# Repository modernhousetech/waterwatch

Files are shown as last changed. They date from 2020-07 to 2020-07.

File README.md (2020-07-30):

# WaterWatch
[Please note that the project while working, is not complete at this point, and has not been fully tested or debugged. The Home Assistant code and the Node-RED code has not been posted yet, but it will be soon. The documentation below is incomplete. There will be more to come] 

WaterWatch Home device ready for installation

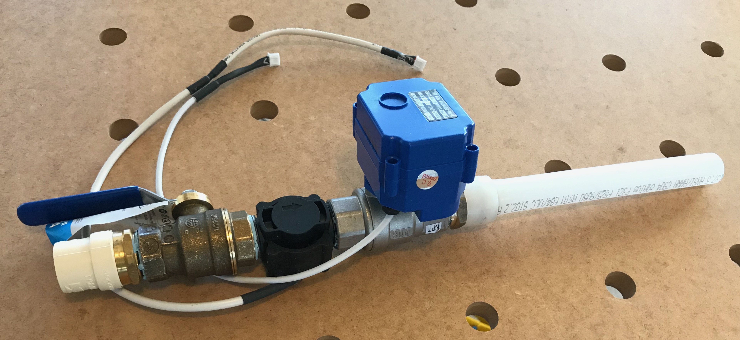
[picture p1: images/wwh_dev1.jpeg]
WaterWatch Home device ready for installation


## Introduction
WaterWatch is a hardware/software project to monitor home water usage and to automatically turn off the water supply if a leak is suspected.

There are two versions of the project. One that monitors and protects irrigation (wwi) and another that monitors and protects a whole house (wwh). The wwi project is much simpler, although it does require a third-party smart irrigation device to integrate with. The wwh project has its own motorized valve and attempts to protect water leaks of all kinds including irrigation leaks.

The wwh device installs at your home's water entrance location. The wwi device installs right before your existing irrigation valves. While the wwh device does provide irrigation leak protection, there is utility in having both devices installed in a single home. The wwi device will give you better irrigation water usage values and times than the wwh device, and it will give you additional protection as it can monitor irrigation with greater precision. The wwi device, of course, offers no protection against household leaks.

Features:
* Automatically shuts off water flow based on a wide variety and extensible criteria
* Uses open and popular IOT and smart home standards and technologies
* Integrates with third-party devices and sensors such as water leak sensors and smart irrigation systems
* Integrates into the major smart home user interface devices such as Alexa and Google Assistant
* Accumulates hourly and daily water usage totals. These are sent to the controller on an hourly basis and are also stored in the device and are available on demand
* Accumulates session water usage totals. WaterWatch automatically creates anonymous sessions based on continuous water usage that meets a certain threshold. For instance, if someone showers there will be a water flow start and a stop. If during that start and stop there is sufficient water usage, then WaterWatch will consider that a "session" and will report it to the controller (Home Assistant). The controller can then report that to the user and also calculate costs based on current water rates. Another useful example of an anonymous sessions would be something like filling up a hot tub. How much water did you use and at what cost? Since WaterWatch Home monitors the water flow of the entire house and other water can flow simultaneously, common sense will have to be used to know if the session was truly just one water event.
* Accumulates named session water usage totals. A named session is similar to an anonymous session except the start and stop times are specified by the controller, and it is given a name. The usefulness of this feature can probably best be explained using an example. Your washing machine (an ordinary non-smart appliance) is connected to a smart plug that monitors power usage. When Home Assistant determines that the washing machine has started a wash (based on power usage data sent from the smart plug) it notifies WaterWatch that a washer load has started. WaterWatch then tells the WaterWatch device to start a named session called "Washer." When Home Assistant subsequently notifies WaterWatch that the load is finished, WaterWatch will tell the device to stop the session. The device then notifies the controller of all water that was used during the start and stop times. WaterWatch then notifies the user of the amount and cost of water used during the wash, as well as the electrical power cost. As mentioned above, common sense needs to be used to know if the water usage was from just the washing machine.

The project uses the following technologies:

Hardware both wwi and wwh:
* [ESP32 development board](https://www.amazon.com/s?k=esp32&i=electronics) 
* [Water flow meter](https://www.amazon.com/gp/product/B079HFY2TY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)
* Various electronic parts and wire
* Various plumbing connectors

Hardware wwh only:
* [Motorized valve](https://www.amazon.com/gp/product/B071YBPDSL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) 
* [Water leak sensors](https://www.amazon.com/gp/product/B07D39MSZS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) (optional) We've used Aqara sensors which also require an Aqara hub. Integration to the WaterWatch system is through Home Assistant and Node-RED. Any detector that integrates into Home Assistant could be used.

Software:
* [Esphome](https://esphome.io) Esphome is a device software development platform. We define our sensors and other devices using esphome yaml syntax and then transition the logic to the C++ code.
* [MQTT](http://mqtt.org) Communication to and from The WaterWatch WiFi device is through the MQTT protocol.
* [Node-RED](https://nodered.org) The logic outside of the device is written in Node-RED. Node-RED is a well-supported, open-source IOT platform. Programming in Node-RED is primarily in Javascript.
* [Home Assistant](https://www.home-assistant.io) Home Assistant is a well-supported, open source, smart home platform that allows us to integrate our device and code with the many other devices and sub-systems that Home Assistant supports. It also provides us a UI and notification platform, and hosts the MQTT server and Node-RED.

Detailed software design instructions will follow.

## Overall design

A one line communication diagram is: device<->MQTT<->Node-RED<->Home Assistant

At its most basic, the project produces an ESP32 device that connects to a water flow sensor and controls a motorized water valve (wwh only). It communicates using WiFi to an MQTT server, which in turn communicates with the smart home system (Home Assistant). 

When water flow or usage exceeds the values provided by the smart home software, the device acts by sending an alarm and (on the wwh device) turning off the valve.

The software in the smart home system is more sophisticated because we can leverage reliable systems in the smart home software, such as occupancy sensors, the on/off status of water using appliances (such as washing machines), irrigation valves that are open, and smart phone and smart device notification features (such as Alexa and Google Assistant). For instance, when the smart home software sets a state of "house is unoccupied" then WaterWatch can tell the WaterWatch device to alarm on *any* water usage (or very little to accommodate running washers and dishwashers). If our washer is powered on, then the smart home software can detect that and we can allow a specific amount of water flow while it is on. 

The smart home software can also integrate WaterWatch with water detection monitors. When a sensor detects water (under a sink for instance), WaterWatch is notified and it will instruct the device to turn off the house water valve.

In the future we would like to implement "signature" water flow events. A very simple signature event would be, for instance, a toilet flush. The water flow increases a certain amount for certain amount of time. When that is detected we know what that water flow was and we can then do something with this information. At this point we can send a water flow "signature" to the device, but the actual detection of the event is only partially implemented. 

### Prerequisites

* Home Assistant running an MQTT server and hosting Node-RED. It would possible to adapt WaterWatch to other smart home platform, such as OpenHAB, that can use MQTT or Node-RED.

* [Esphome setup for a command-line environment](https://esphome.io/guides/getting_started_command_line.html). While the web based ESPHome dashboard usage of Esphome would work, that feature loses it utility for a project that supports multiple configurations, is more complex than just one or more sensors reporting status, and is mostly C++ based.

### WaterWatch Home (wwh) hardware design

WaterWatch Home (wwh) device ready for installation

WaterWatch Home (wwh) ready for installation

This particular unit will attach to the existing house plumbing at the water house entrance using PVC from the street and Uponor PEX to transition to the house's copper piping. The small black device in the middle is the water flow sensor and the blue and metal device is the motorized valve. Both of these devices attach to the WaterWatch CPU using the white cables visible in the image. The manual valve in the image is not necessary for the WaterWatch system, but is there to replace an existing manual valve at the installation location.

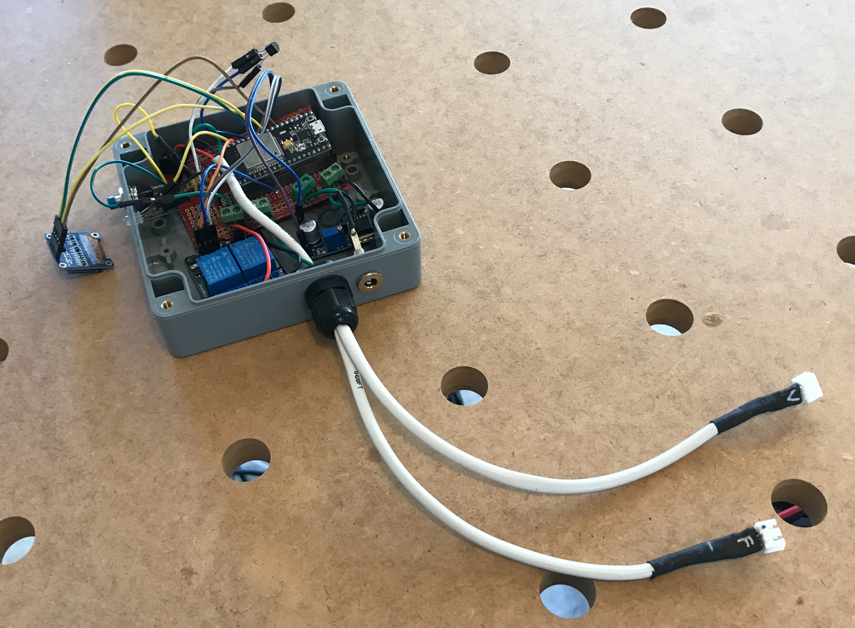
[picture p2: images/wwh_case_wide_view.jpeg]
WaterWatch Home CPU


WaterWatch Home CPU

#### Prerequisites

#### Plumbing Components:

#### CPU Components:
* ESP32 Board[ESP-32S-Development-Board](https://amzn.to/3go0uMI)
* [2 Channel Relay](https://amzn.to/2ztyLcZ)
* [Buck converter LM2596](https://amzn.to/2yAE8Xq)
* [12v-Power-Supply-Single](https://amzn.to/3d2AhkF) These are excellent power supplies that put out a reliable steady 12 volts
* or [12v-Power-Supply-5-pack](https://amzn.to/2X5wtdf) If you need more than two then this five pack is a good deal
* [OLED LCD Display](https://amzn.to/2ZzWX85)
* [Dallas-Temperature-Sensor DS18B20](https://amzn.to/3egIFNS) 
* [PCB-Mount-Screw-Terminal](https://amzn.to/2TA10xv)
* [DC-Power-Jack-Socket](https://amzn.to/2zim1pF)
* [Momentary-switch](https://amzn.to/2TCt973)
* [3-Conductor-Cable](https://amzn.to/3gnVBUa)
* [Cable-Gland](https://amzn.to/2Zy9t89)
* [Hook-up-Wire-Kit](https://amzn.to/36udw76)
* [Breadboard](https://amzn.to/2TAdzZE)
* or [Breadboard-kit](https://amzn.to/3eeRYhd)
* [Dupont-cables](https://amzn.to/2XqUVo3)
* [Cable-connectors](https://amzn.to/2yA37Kw) Other suitable three conductor connectors will do -- this is just what I used. These work well, although they are not waterproof. If weather-proofing is needed, I recommend sealing the connection with heat shrink tubing over a water-resistant non-conductive gel (or ordinary caulk which should be non-conductive once dry), then labeling the joint so the next user knows where it is detachable.
* [Crimping-tool-for-above](https://amzn.to/3ehfoCQ) 
* [Enclosure](https://amzn.to/2XFp3MT) While this is not the enclosure I used in the image, it is of a similar size (120mm x 120mmm x 60mm, external). I had to trim the breadboard to get it to fit in the enclosure you see in the image, so either this size board or the component layout is not perfect. 

### WaterWatch Irrigation (wwi) hardware design

#### Prerequisites

* A smart irrigation device that integrates into the same smart home platform used for WaterWatch.

Copyright 2020 Brenton Olander

[The Amazon links above are affiliate links, which means that I get a little bit of money from Amazon should you purchase using the link. The price for you will be exactly the same whether you purchase using the link or not. If it is convenient for you to purchase using the link then thank you very much.]

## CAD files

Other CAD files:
3d_models/wwi_mini.skp

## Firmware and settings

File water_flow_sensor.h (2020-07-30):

#pragma once

#include "esphome.h"
#include "pulse_counter_sensor.h"
using namespace esphome;
using namespace sensor;
using namespace pulse_counter;
#include "translation_unit.h"
#include "signature.h"

// This is the units per minute water flow value when presumably there is no water flow.
// If the plumbing system is working correctly this should be zero.
extern pulse_counter::pulse_counter_t* g_pulses_base;



class WaterflowSensor: public pulse_counter::PulseCounterSensor {

    // wf_off mode or wf_on mode. 
    // wf_off mode is when water flow <= 0 and wf_on mode is when water flow > 0

    bool in_wf_on_mode_ = false;

    int pin_;
    TranslationManager& xlate_mgr_;
    SignatureManager signature_mgr_;

    static constexpr float report_period_wf_off_mode_secs_default_ = 15.0f;
    static constexpr float report_period_wf_on_mode_secs_default_ = 2.0f;


    // We get updates every <update_interval_default> but report at
    // schedule below when we are in wf_off mode
    float report_period_wf_off_mode_secs_ = report_period_wf_off_mode_secs_default_; 
    float report_period_wf_on_mode_secs_ = report_period_wf_on_mode_secs_default_; 

    static constexpr float update_interval_secs_default_ = 1.0f;

    float update_interval_secs_ = update_interval_secs_default_; 

    struct ReportPeriod {

        pulse_counter_t pulses_total_ = 0.0f;
        int secs_ = 0;
        int last_report_period_secs_ = 0.0f;
        bool report_only_on_change = false;
        
        // Special to report on next add call
        // Currently this is used to get an initial
        // report as soon as possible on start-up so
        // user can see something when we start.
        bool report_on_next_add = false;

        static const int wf_is_changed_delta_ = 10;

        int report_period_secs_;

        pulse_counter_t last_pulses_ = -1;

        ReportPeriod(int report_period_secs):
            report_period_secs_(report_period_secs) {
            reset();
        }

        void set_report_period_secs(int report_period_secs) {
            report_period_secs_ = report_period_secs;
        }

        int get_report_period_secs() const {
            return report_period_secs_;
        }

        int get_last_report_period_secs() const {
            return last_report_period_secs_;
        }

        bool is_report_only_on_change() const { return report_period_secs_ == 0; }

        bool add(pulse_counter_t pulses, int secs) {
            pulses_total_ += pulses;
            secs_ += secs;
            bool change_of_pulses = abs(last_pulses_ - pulses) > wf_is_changed_delta_;
            last_pulses_ = pulses;

            // ESP_LOGD("main", "report_period.add(%i) pulses_total=%i, secs total=%i"
            //     ", last_pulses=%i, change=%i, report_on_change=%i"
            //     ", report_period_secs=%i", 
            //     pulses, pulses_total_, secs_ , last_pulses_,  change_of_pulses,
            //     is_report_only_on_change(), report_period_secs_);  

            bool report = (is_report_only_on_change() && change_of_pulses) 
                || secs_ >= report_period_secs_ || report_on_next_add;
            report_on_next_add = false;

            return report;
        }

        float get_value_as_pulses_per_minute() {

            return (60.0f * pulses_total_) / float(secs_);
        }

        void reset() {
            pulses_total_ = 0;
            last_report_period_secs_ = secs_;
            secs_ = 0;
            last_pulses_ = -1;
        }
    } report_period_;

    public:

    WaterflowSensor(int pin, TranslationManager& xlate_mgr):
        pin_(pin),
        xlate_mgr_(xlate_mgr),
        signature_mgr_(xlate_mgr_),
        report_period_(report_period_wf_off_mode_secs_) {

        set_name("wf");
        set_unit_of_measurement("pulses/min");
        set_icon("mdi:pulse");
        set_accuracy_decimals(2);
        set_force_update(false);
    }

    void on_start_init( int report_period_wf_off_mode_secs,
                        int report_period_wf_on_mode_secs ) {

        ESP_LOGD("main", "on_start_init(%i, %i)",  
          report_period_wf_off_mode_secs, report_period_wf_on_mode_secs);
        set_pin(new GPIOPin(pin_, INPUT, false));

        set_report_period_wf_off_mode_secs(report_period_wf_off_mode_secs);
        set_report_period_wf_on_mode_secs(report_period_wf_on_mode_secs);
        report_period_.set_report_period_secs(report_period_wf_off_mode_secs_);
        // We want to report (publish) initially as soon as possible so
        // user can see something.
        report_period_.report_on_next_add = true;

        set_update_interval_secs(1);
        
        set_in_wf_on_mode(false);

        set_rising_edge_mode(pulse_counter::PULSE_COUNTER_INCREMENT);
        set_falling_edge_mode(pulse_counter::PULSE_COUNTER_DISABLE);
        set_filter_us(13);
    }

    // Modes:
    //      Normal
    //      Fast
    //      on change
    //      never on zero (=< base flow)
    void update() override {
        pulse_counter_t pulses = this->storage_.read_raw_value();

        if (report_period_.add(pulses, update_interval_secs_)) {
            float value = xlate_mgr_.current->convert_pulses_to_uom(report_period_.get_value_as_pulses_per_minute());
            // reset() below will save the secs of this period which
            // the app will retrieve using get_last_period_secs(). This is a
            // bit of  kludge which we use because we can't, as far as I know,
            // send more information when we publish_state(). TODO: we could easily use
            // an alternative to publish_state() to get this data to the app.
            report_period_.reset();
            this->publish_state(value);
        }

        //float value = (60000.0f * raw) / float(this->get_update_interval());  // per minute
        //value = xlate_->convert_pulses_to_uom(value);

        //if (!only_publish_on_change || )
        if (pulses > *g_pulses_base && !in_wf_on_mode()) {
            set_in_wf_on_mode(true);
        } else if (pulses <= *g_pulses_base && in_wf_on_mode()) {
            set_in_wf_on_mode(false);
        }

        // ESP_LOGD("main", "pulse counter: %i pulses,wf_on_mode(%i), rps(%i)", 
        //   pulses, in_wf_on_mode(), report_period_.get_report_period_secs());
        
    }

    void convert_uom(const char* from, float old_calibrate_factor=0) {
        signature_mgr_.convert_uom(from, old_calibrate_factor);
    }

    int get_report_period_secs() const {
        return report_period_.get_report_period_secs();
    }

    int get_last_report_period_secs() const {
        return report_period_.get_last_report_period_secs();
    }

    void set_report_period_wf_off_mode_secs(float secs) {
        report_period_wf_off_mode_secs_ = secs; 
        if (!in_wf_on_mode()) {
            report_period_.set_report_period_secs(report_period_wf_off_mode_secs_);
        }
    }
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

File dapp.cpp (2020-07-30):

// Copyright 2020 Brenton Olander

#include "esphome.h"
#include "dapp.h"


#define FW_VERSION_BASE "0.05.22"

#ifdef APP_DEBUG_MODE
#define FW_VERSION_DEBUG FW_VERSION_BASE"-D"
#else
#define FW_VERSION_DEBUG FW_VERSION_BASE
#endif

#if LOG_LEVEL > LOGLEVEL_HIGHEST_RELEASE_LEVEL
#define FW_VERSION FW_VERSION_DEBUG"-L:D"
#else
#define FW_VERSION FW_VERSION_DEBUG
#endif 

//#ifdef gpio::GPIOSwitch::GPIOSwitchRestoreMode
extern gpio::GPIOSwitch *valve_open;
extern gpio::GPIOSwitch *valve_close;
//#endif


dApp dapp;

#ifdef APP_LOG
AppLog app_log;
#endif

// Mirrors dapp.upm_base for the benefit of WaterUsage
float* g_upm_base;
pulse_counter::pulse_counter_t* g_pulses_base;

///////////////////////////////////////////////////////////////////////////////////////////
dApp::dApp() {

    // Global cheat for WaterUsage objects
    g_upm_base = &upm_base_;
    g_pulses_base = &pulses_base_;
}


// Called at on_boot level 600 where sensors are setup but wifi (and mqtt) are not
void _entry_point dApp::on_boot(const char* app, int wf_report_wf_off_interval_secs, int wf_report_wf_on_interval_secs) {

    APP_LOG_ENTER("on_boot()");

    SetStatusLED(1.0, 1.0, 1.0);

    app_ = app;

    wf_->on_start_init(wf_report_wf_off_interval_secs, wf_report_wf_on_interval_secs);

    calc_max_plus_values();

    makeMqttTopics(mqtt_client->get_topic_prefix());

    SetStatusLEDBasedOnValveStatus();

    on_boot_called = true;

    APP_LOG_LOG("} on_boot(app=%s, wf_off_interval_secs=%i, wf_on_interval_secs=%i", app,
      wf_report_wf_off_interval_secs, wf_report_wf_on_interval_secs); 

    APP_LOG_EXIT("on_boot");
  }


  void dApp::makeMqttTopics(const std::string& prefix) {

    mqtt_topic_prefix_ = prefix;

    mqttTopicClosedUsageState_ = prefix + mqttTopicClosedUsageState_;
    mqttTopicStat_ = prefix + mqttTopicStat_;
    mqttTopicProp_ = prefix + mqttTopicProp_;
    mqttSensorWfOverlimitStatus_ = prefix + mqttSensorWfOverlimitStatus_;
    mqttSensorWfCurrentUsageState_ = prefix + mqttSensorWfCurrentUsageState_;
    mqttSensorWfHourlyUsageStatus_ = prefix + mqttSensorWfHourlyUsageStatus_;
    mqttSensorWfDailyUsageStatus_ = prefix + mqttSensorWfDailyUsageStatus_;
    mqttSensorWfSessionUsageState_ = prefix + mqttSensorWfSessionUsageState_;
    mqttSensorWfNamedUsageState_ = prefix + mqttSensorWfNamedUsageState_;

  }

/* 
  Properties {

    [See https://en.wikipedia.org/wiki/List_of_tz_database_time_zones ]
    "timezone": "America/Phoenix",

    [Hourly usage totals can be saved in array in device.
    Use mqtt topic "<topic-prefix>/cmnd/get_closed_periods" to have
    waterwatch send array in mqtt json message topic
    "/sensor/wf/closed_usage/state".
    Use mqtt message topic "<topic-prefix>/cmnd/clear_closed" to
    clear this array and session array.]
    "closed_periods_max": 48,

    [Waterwatch supports 'gal' for gallons and gpm and 'L' for liters and lpm]
    "unit_of_measure": "gal",

    [Maximimum water flow. When above this level
    waterwatch will send out an alarm in mqtt topic
    "sensor/wf/over_limit/status" with payload "on" or "off"]
    "water_flow_max": 1.0,

    [At or below this level is considered "no water flow".
    Normally this should be 0, but a tolerance is permitted using
    this property in case zero is not possible perhaps because of a 
    leak that is not fixed immediately.]
    "water_flow_base": 0.0,

    [Adjust device water flow and usage using this value in case
    what waterwatch thinks is a gallon or a liter is not what you. 
    measure. Examples: 1.0 is unadjusted, 1.1 is a 10% adjustment upwards,
    0.9 is a 10% adjustment downwards. For instance, if you measure
    .5 gallons and waterwatch reports 1 gallon, you would use a 
    calibrate_factor of 0.5]
    "calibrate_factor": 1.1,


    [How long in seconds does an overlimit condition have to exist 
    before an alarm is raised? The integral "reporting period" in
    waterwatch is 15 seconds. "test_period_secs" must be a multiple
    of this reporting period. The default is the reporting period
    of 15 seconds. False alarms can also be avoided using the
    "initial_surge_secs" property.  ]
    "test_period_secs": 30,

    [If pipes are empty there can sometimes be an initial 
    surge of over limit water flow as the pipes are filled. 
    This propery allows a "grace" period when water first
    starts to flow to account for this. After water is flowing
    this property is ignored and only "test_period_secs" is
    observed.]
    "initial_surge_secs": 15,

    [Waterwatch keeps track of the water usage during a continuous period 
    of irrigating which we call a session. The next three properties
    control this feature]

    [How many sessions to save before overwriting oldest]
    "closed_sessions_max": 14

    [Sessions shorter than min_secs will be thrown out]
    "min_session_secs": 420,

    [When one zone valve closes and another opens there
    may be no water flow. How long to allow for this. (in
    the future these subs zones will alse be saved)]
    "end_session_secs": 180

    [How often we report water flow in seconds. "wf_off" mode is
    when there is no water flow, wf_on mode is when there is water flow.
    A value of 0 means to report only on change of flow. 
    Defaults in the code are: wf_off = 15, wf_on = 2. There are
    defaults in the common_substitutions.yaml as well that override the 
    code. At last check they are wf_off = 180, wf_on = 2
    (TODO: would it be better to use 0 to 
    mean "never report" and a negative number to mean "on change only"?)]
    "report_period_secs": {
      "wf_off": 0,  
      "wf_on": 0   
    }

    Other items needed:
      cmmd/signature/add
      cmmd/signature/remove

      cmmd/delete_signature
      [ {
        "name": "Shower",
        "uom": "gpm",
        "ver": 1
        "segments": [
          [<upm>, <upm_allowance>, <duration_ms>, <duration_allowance_ms>],
          ...
        ]} 
  }
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
